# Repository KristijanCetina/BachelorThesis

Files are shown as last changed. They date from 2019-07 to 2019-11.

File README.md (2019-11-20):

# BachelorThesis

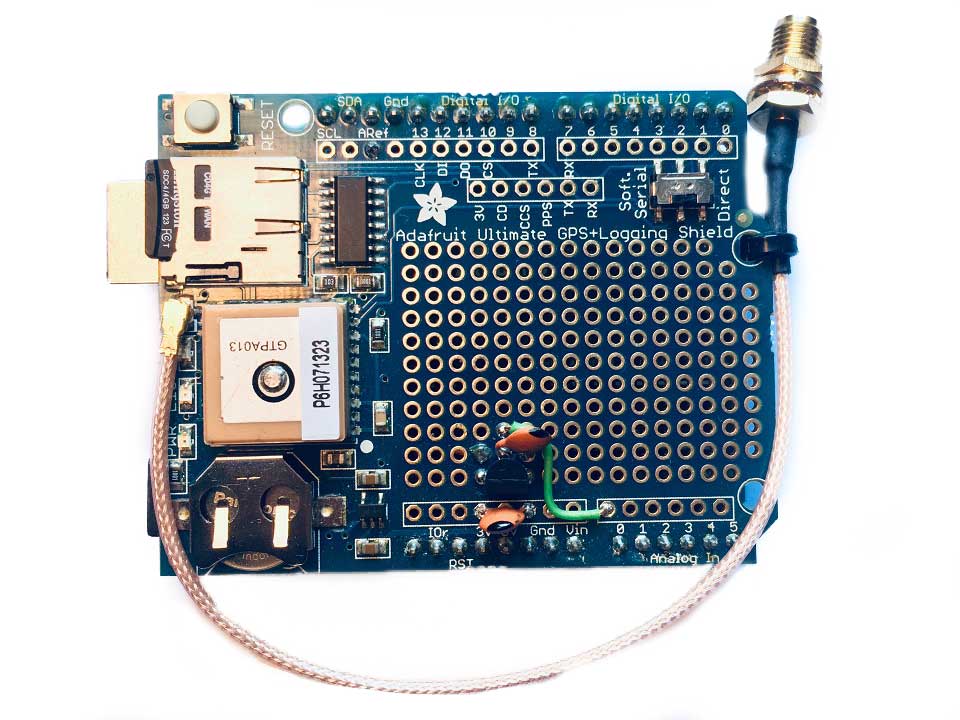
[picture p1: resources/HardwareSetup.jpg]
Hardwareski sklop

Završni rad stručnog studija Politehnike koji se izvodi pri [Istarskom Veleučilištu](https://www.iv.hr/)

Na sljedećem linku je dostupna [PDF verzija rada](https://github.com/KristijanCetina/BachelorThesis/blob/master/report/Zavr%C5%A1niRad-KristijanCetina.pdf)

Najlakši način za preuzeti ovaj rad ukoliko koristite git je putem sljedeće naredbe

``` bash
git clone https://github.com/KristijanCetina/BachelorThesis.git [<directory>]
```

pri čemu je `[<directory>]` neobavezan parameter - željeno ime projekta.

U suprotnom možete preuzeti cijeli kao .zip datoteku klikom na `Download`

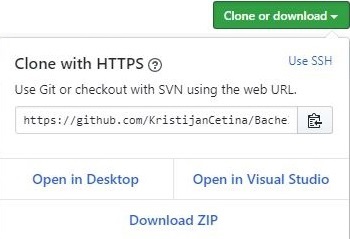
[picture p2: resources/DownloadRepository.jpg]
Download


## Summary

Prikupljanje, obrada i vizualizacija podataka nalazi se na svakom koraku našega života.
U ovom radu prikazan je postupak izrade snimača podataka koristeći Arduino platformu te obrada podataka koristeći isključivo alate otvorenog i slobodnog koda.
Hardwareska platforma trenutno koristi GPS prijemnik i temperaturni senzor te se u budućnosti planira povećanje broja senzora.
Podatci koji se skupljaju na uređaju spremaju se lokalno na memorijsku karticu ne bi li se kasnije analizirali na računalu pri čemu se koristi programski jezik Python unutar Jupyter notebook okruženja uz pomoć Pandas, NumPy i Matplotlib biblioteka.
Izrađeni alat za analizu radi na svim popularnim operacijskim sustavima danas u upotrebi.

U duhu otvorenog koda i dobre prakse znanstvene zajednice ovaj rad je napisan koristeći LaTeX sustav te je kompletan rad hostan na GitHub-u i slobodano dostupan svim zainteresiranim stranama koji žele nastaviti rad na ovoj temi.

### Ključne riječi

`Arduino, Python, Matplotlib, open-source, obrada podataka`

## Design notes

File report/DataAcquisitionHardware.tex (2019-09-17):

\chapter{Prikupljanje podataka - hardware}\label{ch:Hardware}
\begin{figure}[h]
\begin{center}
.jpg}
\caption{Izgled korištenog hardwareskog sklopa}\label{pic:HardwareSetup}
\end{center}
\end{figure}
Na slici \ref{pic:HardwareSetup} prikazan je zgotovljeni hardwareski sklop korišten u ovom radu.
Ispod GPS prijemnika s utorom za microSD karticu i prototipnim područjem nalazi se Arduino UNO mikrokontroler.
Za bolji prijem signala korištena je GPS antena, a za spajanje se koristi adapterski kabel (\textit{pigtail}).
Dodatno se može vidjeti temperaturni senzor TMP36 zajedno s filter kondenzatorima.

U prilogu \ref{ArduinoSource} prikazan je cjeloviti izvorni kod koji se izvšvana na Arduino mikrokontroleru.

\section{GPS logging shield}

\begin{figure}
.pdf}
\caption{Shema Adafruit GPS Logger Shield}\label{shema:AdafruitLoggerShield}
\end{figure}

Na shemi \ref{shema:AdafruitLoggerShield} nalazi se shema gotovog elektroničkog sklopa kako dolazi iz tvornice\footnote{Kompletna dokumentacija dostupna je na \url{https://learn.adafruit.com/adafruit-ultimate-gps-logger-shield?view=all}}$^,$\footnote{GitHub repozitorij korištene verzije dostupan na \url{https://github.com/adafruit/Adafruit-GPS-Logger-Shield-PCB}}.
Na samoj tiskanoj pločici postoji takozvano prototipno područje za dodavanje vanjskih elemanata čiji je raster 2.54 mm koji odgovara standardu \textit{through-hole} elemenata.
Na to područje je dodan temperaturni senzor TMP36\footnote{Datasheet dostupan na \url{https://github.com/KristijanCetina/BachelorThesis/blob/master/resources/TMP35_36_37.pdf}}\label{ftn:TMP36Datasheet} zajedno s dodatnim pasivnim elementima koji služe kao filter smetnji koje se javljaju u radu zbog okoline.
Shema spoja je prikazana na slici \ref{shema:TMP36}.

\section{Prikupljanje podataka o temperaturi}\label{sec:TempData}
\begin{figure}[!ht]
\begin{center}
.jpg}
\caption{Shema spoja TMP36 senzora}\label{shema:TMP36}
\end{center}
\end{figure}
Kako svaki elektronički sklop ima definirani raspon radne temperature važno je znati u kojim se uvjetima isti nalazi.
Ukoliko je temperatura previsoka, može se uključiti aktivno hlađenje, ili, ako se unaprijed zna da će se sklop nalaziti pod povišenom radnom temperaturom tada se može konstrurati adekvatan sustav hlađenja.
Isto vrijedi za prenisku temperaturu.
Prema ranije spomenutoj shemi \ref{shema:TMP36}, dodan je temperaturni senzor koji mjeri radnu temperaturu okoline uređaja.
Pri testiranju, ova vrsta senzora pokazala se veoma pouzdanom, uz minimalno samozagrijavanje koje bi utjecalo na točnost mjerene veličine, ali je isto tako pokazala vrlo brze promjene izlazne vrijednosti koja može imati uzrok u vanjskim smetnjama.
Kako bi se otklonio taj problem primijenjena su dva rješenja.
Prvi je hardwareski filter - kondenzatori koji si prikazani na shemi \ref{shema:TMP36}, a drugi je softwareski filter.
Tvornički podatci o izlaznom naponu šuma mogu se pronaći u datasheetu uređaja, slika 20.
Na slici \ref{data:RawWithOutCaps} prikazane su izlazne vrijednosti senzora bez ikakvog filtriranja i obrade.
Frekvencija uzorkovanja je 10Hz (10 očitanja u sekundi)
Svakako nije realno za očekivati da se temperatura mjenja sukladno očitanim vrijednostima.

\subsection{Softwareski filter}
Softwareski filter radi na principu očitavanja 10 vrijedosti sa senzora te ih sprema u polje.
Potom ih sortira po veličini i uzima medijan\footnote{Medijan (mediana, centralna vrijednost) je pojam iz statistike koji određuje sredinu distribucije.
Pola vrijednosti skupa (distribucije) nalazi se iznad mediane, a pola ispod} vrijednost kao točnu temperaturu.
Time se eliminiraju sve vrlo visoke i vrlo niske vrijednosti koje se mogu pojaviti zbog šuma u signalu.
Vrijednosti se čitaju svakih 100 ms te uz računanje na bazi 10 vrijednosti daju frekvenciju od 1 očitanja u sekundi koja odgovara i frekvenciji uzorkovanja podataka s GPS senzora.
Prilikom testiranja utvrđeno je da veći broj uzoraka ne doprinosti kvaliteti izmjerenih vrijednosti, dok se pri manjem broju uzoraka može se potkrasti poneka nerealna vrijenosti.
Kako je očekivano vrijeme promjene temperature značajno duže od 1 sekunde onda su prihvaćene navedene vrijednosti i metoda filtriranja.
Na slici \ref{data:FilteredWithOutCaps} prikazane su izlazne vrijednosti senzora nakon primjene opisanog softwareskog filtera.
Primijeti se značajno manje skokova od nečega što se može smatrati stvarnom vrijednosti. 

\begin{figure}[!h]
\begin{minipage}{0.49\linewidth}
.jpg}
\caption{Vrijednosti senzora bez \mbox{filtriranja}}\label{data:RawWithOutCaps}
\end{minipage}
\hfill
\begin{minipage}{0.49\linewidth}
.jpg}
\caption{Vrijednosti senzora sa \mbox{softwareskim} filtriranja}\label{data:FilteredWithOutCaps}
\end{minipage}
\end{figure}

\subsection{Hardwareski filter}
Filter je jednostavna mreža keramičkih kondenzatora vrijednosti $10 pF$ koji su spojeni što bliže senzoru između izvoda za napajanje i izlaza senzora prema točki nultog potencijala (\textit{GND, masa}) kako bi apsorbirali eventualne smetnje.
Iako je softwareski filter u nekim situacijama dovoljno dobar, ovo jednostavno i jeftino rješenje daje dodatni sloj filtriranja koji za posljedicu ima vrlo glatko očitanje temperature bez skokova u vrijednostima.

Primjenom kombinacije softwareskog i hardwareskog filtriranja postignuta je vrlo zadovoljavajuća karakteristika dobivenih stabilnih vrijednosti bez nerealnih skokova i s vrlo glatkom tranzicijom kod grijanja ili hlađenja sklopa. Dobivene vrijednosti prikazane su na slici \ref{data:FilteredWithCaps}.
\begin{figure}[!h]\begin{center}
.jpg}
\caption{Vrijednosti senzora primjenom kombinacije Sw i Hw filtera}\label{data:FilteredWithCaps}
\end{center}\end{figure}

\section{Prikupljanje GPS podataka}
GPS\footnote{Global Positioning System - Sustav globalnog pozicioniranja} je javni sustav u vlasništvu vlade SAD-a\footnote{\url{https://www.gps.gov}} koji služi globalnom pozicioniranju temeljen na satelitima s atomskim satovima koji odašilju vrlo točno i precizno trenutno vrijeme te su sinkronizirani sa zemaljskim satovima. 
Bilo kakva odstupanja se korigiraju na dnevnoj bazi.
Prijemnik prima signal satelita te izračunava točnu poziciju temeljenu na poznatoj poziciji satelita i razlikama u primljenim vremenima od svakog satelita.
Minimalno su potrebna 3 satelita za dobivanje koordinata i 4 satelita za dobiti pozicija o nadmorskoj visini prijemnika.

U ovom radu korišten je GPS chip MTK3339\footnote{\url{https://cdn-shop.adafruit.com/datasheets/GlobalTop-FGPMMOPA6C-Datasheet-V0A-Preliminary.pdf}} integriran na prije spomenuti Adafruit Ultimate GPS Logger Shield.

Kao koristan izlaz prijemnik daje NMEA\footnote{\url{https://www.nmea.org/content/STANDARDS/NMEA_0183_Standard}} rečenicu. 
Ovisno o potrebnim podatcima, mogu se koristiti razne rečenice, a u ovoj primjeni korištena je \$GPRMC\footnote{\url{http://aprs.gids.nl/nmea/}} koja daje minimalne potrebne podatke, a među kojima su vrijeme (UTC) i datum, trenutna pozicija i brzina.
Primjer \$GPRMC rečenice je \begin{verbatim}
$GPRMC,053005.000,A,4457.8784,N,01356.1351,E,36.41,124.90,310719,,,A*58
\end{verbatim}
pri čemu je:
\begin{tabbing}
\hspace{80pt}\=\kill
 \$GPRMC \> Oznaka rečenice \\ 
 053005.000 \> UTC vrijeme (7:30:05 lokalno)\\ 
 A \> Oznaka valjanosti, A = OK, V = warning \\ 
 4457.8784,N \> Zemljopisna širina \\ 
 01356.1351,E \> Zemljopins dužina \\ 
 36.41 \> Brzina u čvorovima ($\approx 67 km/h$)\\ 
 124.90 \> Smjer kretanja \\
 310719 \> Datum (31. srpnja 2019.)\\
 A*58 \> Checksum (kontrolni broj)
\end{tabbing} 
Prilikom provjere primljenih podataka obavezno se provjerava
\begin{itemize}
\item da li primljeni checksum odgovara izračunanom za datu rečenicu kako bi se izbjegle pogreške u komunikaciji,
\item je li oznaka valjanosti \textit{A} što znači da uređaj ima prijem s dovoljnog broj satelita da se primljenim podatcima može vjerovati.
\end{itemize}
Provjeru valjanosti i checksuma vrši biblioteka dostupna za Arduino platformu zajedno s ostalom dokumentacijom uređaja te nije bilo potrebno pisati poseban kod koji će to raditi.

\section{Spremanje podataka na memorijsku karticu}
Na korištenom Adafruit Ultimate GPS Logger Shieldu postoji utor za microSD memorijsku karticu koja se koristi za zapisivanje prikupljenih podataka kako bi se isti mogli kasnije obraditi i prikazati.
Sustav prikupljene podatke sprema na memorijsku karticu u .csv \footnote{Comma Separated Values} formatu pogodnim za kasniju obradu putem Excel programskog alata ili drugih alata za obradu i vizualizaciju podataka.
Svaki red predstavlja jedan zapis, a u odnosu na ranije prikazanu \$GPRMC rečenicu, na kraju je dodan i podatak o trenutnoj temperaturi u $^\circ C$ koja je očitana sa senzora opisanog u poglavlju \ref{sec:TempData}.
Frekvencija zapisivanja podatka je postavljena na 1 zapis u sekundi.
Datoteka se automatski kreira prilikom uključivanja sklopa ako je SD kartica prisutna.
Ime datoteke je GPSLOG\textit{XX}.csv pri čemu je \textit{XX} broj koji počinje od 00 i uvećava je za 1 kod svakog pokretanja. 
Testiranje je pokazalo da veličina datoteke s 10 sati ($\approx 36000$ zapisa) snimljenih podataka iznosi otprilike 2.7 MB.

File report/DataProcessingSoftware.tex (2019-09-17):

\chapter{Obrada podataka - software}\label{ch:Software}
Kako je već spomenuto u uvodu i opisu korištenih tehnologija, analiza podataka izrađena je koristeći Python programski jezik unutar Jupyter Notebook interaktivne bilježnice uz dodatak Numpy biblioteke za numeričku analizu i Matplotlib biblioteke za izradu grafova.

\section{Prikaz podataka vozila u kretanju}
Kao prvi primjer obrade podataka izrađena je analiza kretanja vozila i vizualizirani su prikupljeni podatci.
U dodatku \ref{AnalizaKretanjaVozila} prikazana je cjelokupna analiza podataka te demonstriran završni proizvod koji može biti dalje distribuiran u printanoj verziji ili preferirano u digitalnom obliku koji onda omogućava daljni rad na istome.

Koristeći razne tipove ćelija unutar Jupyter notebooka, stvorena je prikazana analiza.
Tip čelije \textit{Markdown} podržava formatiranje i sintaksu \texttt{.md} Markdown datoteke\footnote{\url{https://www.markdownguide.org/}}, a koje se koriste za opisni dio analize kako bi čitatelj znao o čemu se radi bez potrebe proučavanja programskog koda.

Tip ćelije \textit{Code} omogućuje unošenje i izvršavanje programskoga koda koji će napraviti neku željenu radnju.
Ćelije se mogu izvršavati jedno po jedna ili sve u sekvencijalnom nizu.

Na kraju postoje i \textit{Output} ćelije koje prikazuju izlazni rezultat izvršene \textit{code} ćelije.

Kako bi mogli koristiti navedene dodatne module u Python prvo ih je potrebno uvesti
\begin{lstlisting}[language=Python]
import pandas as pd
import matplotlib.pyplot as plt
from numpy import genfromtxt, arange, sin, pi
from matplotlib import style
from matplotlib import dates as mpl_dates
import numpy as np
from pandas.plotting import register_matplotlib_converters
register_matplotlib_converters()
\end{lstlisting}

Konvencija je da se NumPy biblioteka skrećeno imenuje \texttt{np} kako bi se olakšalo kasnije korištenje u radu.
Isto vrijedi i za ostale često korištene biblioteke.

Nakon toga potrebno je navesti koja se datoteka s podatcima koristi i nazvati stupce podataka 
\begin{lstlisting}[language=Python]
filename='GPSLOG10.CSV'
data=pd.read_csv(filename, header=None, delimiter=',',
names=['Sentence','Time','Validity','Latitue','NS','Longitude','EW',
'Speed','Direction','Date','NA1','NA2','Checksum','Temperature'])
\end{lstlisting}
Pri čemu je \texttt{GPSLOG10.CSV} ime datoteke u kojem su spremljeni podatci.

Nakon uvodnih radnji, spremni smo započeti s analizom podataka i vizualizcijom onih koje nas zanimaju.
U ovisnosti o željenim rezultatima ovisit će i potrebne operacije koje je potrebno poduzeti.
Ponekad su podatci već u takvom formatu da se mogu odmah koristiti, dok je ponekada potrebno napraviti veću ili manju manipulaciju nad njima kako bi bili pogodni za korištenje.
U svakom slučaju, vrlo je važno poznavati strukturu seta podataka koji se koristi kako bi se izbjegle pogreške zbog njegovog nepoznavanja ili korištenja krive mjerne jedinice.
Godine 1999., NASA je izgubila 125 milijuna vrijedan \textit{Mars Climate Orbiter} zbog previda pretvorbe jedinica\cite{sauser2009projects} što samo pokazuje koliko je to realna zamka u koju i najbolji svjetski stručnjaci mogu upasti.
U ovom slučaju, brzina je prikazana u čvorovima što odgovara prijeđenom putu od jedne nautičke milje u sat vremena.
Ukoliko želimo prikazati brzinu u $km/h$ potrebno je izvršiti pretvorbu jedinica.
Jedna nautička milja iznosi 1852 $m$ što znači da zapisanu brzinu treba pomnožiti s 1.852 kako bi dobili $km/s$.

\begin{figure}[!h]\begin{center}
.png}
\caption{Izrađeni graf kretanja vozila}\label{graf:Speed}
\end{center}\end{figure}

Obzirom da je uvijek korisno vizualizirati kretanje veličine na grafu tako je i u ovom radu napravljen graf promjene brzine u vremenu prikazan na \ref{graf:Speed}, što je koristeći Matplotlib vrlo jednostavno.
\begin{lstlisting}[language=Python]
plt.plot(data['Time'],data['Speed']*1.852, 'b-')
\end{lstlisting}
Pri čemu  \textit{data['Time']} predstavlja apcisu grafa, a \textit{data['Speed']} predstavlja ordinatu prikazanog grafa.
\textit{'b-'} je parametar kojim je definirana linija - linija plave boje.
Svaki graf treba biti propisno obilježen pa su tako i na ovom grafu označene vrijednosti i imena osi, prikazane mjerne jedinice i dodana legenda, iako je prikazana samo jedna veličina.

Dodatno, iz dostupnih podataka može se napraviti graf kretanja temperature koji je prikazan u kompletnoj analizi u dodatku \ref{AnalizaKretanjaVozila}.
Osim podataka koji se mogu prikazati grafički, možemo pogledati i ostale statističke podatke kao što su minimalna i maksimalna temperatura tijekom promatranog razdoblja.
\begin{lstlisting}[language=Python]
print ('Minimalna temperatura: ',np.min(data['Temperature']), 'C')
print ('Maximalna temperatura: ',np.max(data['Temperature']), 'C')
\end{lstlisting}
Ovdje su korištene ugrađene funkcije \texttt{min} i \texttt{max} NumPy biblioteke koje za parametar uzimaju set podataka temperature.

Zanima li nas prosječna temperatura tijekom promatranog razdoblja, tada i za to postoji funkcija koja nam olakšava rad.
Umjesto da zbrajamo sve elemente te zbroj dijelimo s brojem elemenata, jednostavno možemo koristiti
\begin{lstlisting}[language=Python]
print ('Prosjecna temperatura: ', '
{:.2f}'.format(np.mean(data['Temperature'])), 'C ',
'{:.2f}'.format(np.std(data['Temperature'])), 'C')
\end{lstlisting}
Pri čemu \texttt{np.mean} daje prosječnu temperaturu, a \texttt{np.std} daje standardnu devijaciju vrijednosti.
\texttt{'{:.2f}'.format} je opcija formatiranja stringa pomoću koje se prikazuje dva decimalna mjesta.

\section{Prikaz podataka lifta}
Analiza prikazana u dodatku \ref{VizualizacijaKretanjaLifta} vizualizira podatke prikupljene mobilnim telefonom koristeći aplikaciju \textit{phyphox}\footnote{\url{https://www.phyphox.org}}.
Korišten je modul koji očitava podatke s akcelerometra u sve 3 osi koordinatnog sustava.
Mobilni uređaj bio je prislonjen na bočni panel lifta i pokušano je postaviti ga da stoj okomito na smjer kretanja sa stražnjom stranom priljubljenim na panel kako bi se dobili čim točniji podatci bez unošenja pogreške zbog pomaknutih osi mobitela i lifta.
Izmjerene vrijednosti predstavljaju put od prizemlja do 5. kata zgrade na adresi Koparska 58, Pula.

Podatci su zatim spremljeni u .csv datoteku te je ista prenesena na računalo.
Datoteka je formatirana na način da ima imena vrijednosti u zaglavlju te su korišteni zadani nazivi, a polja odvojena znakom ";".

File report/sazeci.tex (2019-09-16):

\section*{Sažetak}\label{sazetak_hr}
\addcontentsline{toc}{chapter}{\nameref{sazetak_hr}}
Prikupljanje, obrada i vizualizacija podataka nalazi se na svakom koraku našega života.
U ovom radu prikazan je postupak izrade snimača podataka koristeči Arduino platformu te obrada podataka koristeći iskljućivo alate otvorenog i slobodnog koda.
Hardwareska platforma trenutno koristi GPS prijemnik i temperaturni senzor te se u budućnosti planira povećanje broja senzora.
Podatci koji se skupljaju na uređaju spremaju se lokalno na memorijsku karticu ne bi li se kasnije analizirali na računalu pri čemu se koristi programski jezik Python unutar Jupyter notebook okruženja uz pomoć Pandas, NumPy i Matplotlib biblioteka.
Izrađeni alat za analizu radi na svim popularnim operacijskim sustavima danas u upotrebi.

U duhu otvorenog koda i dobre prakse znanstvene zajednice ovaj rad je napisan koristeći \LaTeX{} sustav te je kompletan rad \textit{hostan} na GitHub-u i slobodano dostupan svim zainteresiranim stranama koji žele nastaviti rad na ovoj temi.

\subsection*{Ključne riječi}\label{kw_hr}
\addcontentsline{toc}{section}{\nameref{kw_hr}}
\textit{Arduino, Python, Matplotlib, open-source, obrada podataka}

\section*{Sommario}\label{sazetak_it}
\addcontentsline{toc}{chapter}{\nameref{sazetak_it}}
La raccolta, l’elaborazione e la visualizzazione dei dati è presente in ogni aspetto della nostra
vita.
In questa tesi è documentata la creazione di uno strumento per la raccolta dati creato su
piattaforma Arduino, e l’elaborazione dei dati raccolti usando esclusivamente strumenti \textit{Open Source}.
La piattaforma hardware attuale usa un ricevitore GPS ed un sensore di temperatura mentre per future evoluzioni è in programma l’incremento del numero di sensori. 
I dati raccolti dallo strumento vengono immagazzinati sulla scheda di memoria per poi essere analizzati sul computer.
Per l’analisi dei dati viene usato il linguaggio di programmazione Python sull' ambiente di programmazione Jupyter notebook, con l’ausilio di biblioteche Pandas, NumPy e Matplotlib.
Lo strumento qui descritto è compatibile con tutti i sistemi operativi piu popolari oggi in uso.

Nello spirito della filosofia Open Source e della cultura scientifica questa tesi e stata scritta usando il sistema \LaTeX{} ed è disponibile liberamente su GitHub per tutti coloro che fossero interessati a continuare il lavoro fatto su questo tema.

\subsection*{Parole chiave:}\label{kw_it}
\addcontentsline{toc}{section}{\nameref{kw_it}}
\textit{Arduino, Python, Matplotlib, open-source, analisi dati}

\section*{Abstract}\label{sazetak_en}
\addcontentsline{toc}{chapter}{\nameref{sazetak_en}}
Data acquisition, processing, and visualization are at every step of our lives.
This paper describes how to record data using an Arduino and analyze them using free and open-source (FOSS) tools exclusively.
The hardware platform is currently using a GPS receiver and a temperature sensor with the planned increase in the number of sensors in the future.
The data collected on the devices is stored locally to a memory card and subsequently analyzed on a computer.
The Python programming language within the Jupyter notebook environment was used for analysis with the help of the Pandas, NumPy and Matplotlib libraries.
The created analysis tool works on all today popular operating systems.

In the spirit of the open-source and good practice of the scientific community, this paper was written using the \LaTeX{} system and a complete project is hosted on GitHub freely available to all interested parties who wish to work on these topic.

\subsection*{Keywords:}\label{kw_en}
\addcontentsline{toc}{section}{\nameref{kw_en}}
\textit{Arduino, Python, Matplotlib, open-source, data analysis}

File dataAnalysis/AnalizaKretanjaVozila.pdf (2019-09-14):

# AnalizaKretanjaVozila

## September 14, 2019

## 1 Analiza podataka kretanja vozila iz .csv filea

### Demo kako uz pomoc python programskog jezika i matplotlib biblioteke za prikaz grafova Prvo uvezemo potrbne bibliteke

[1]: import pandas as pd
import matplotlib.pyplot as plt
import matplotlib as mpl
from numpy import genfromtxt, arange, sin, pi from matplotlib import style
from matplotlib import dates as mpl_dates
import numpy as np
from pandas.plotting import register_matplotlib_converters register_matplotlib_converters()

Unese se ime datoteke s podacima i mapiraju se polja sukladno zapisanome.
U ovom primjeru podaci su razdvojeni s znakom ‘,’ ali cesti je slucaj kada su podaci odvojeni

### nekim drugim znakom te se to treba posebno naznaciti kako bi program znao granice izmedu

polja.

[2]: filename='GPSLOG10.CSV'
#plt.style.use('ggplot')

data=pd.read_csv(filename, header=None, delimiter=',',␣ ,→names=['Sentence','Time','Validity','Latitude','NS', ␣
,→'Longitude','EW','Speed','Direction','Date',
␣
,→'NA1','NA2','Checksum','Temperature'])

### 1.1 Line plot

### Sada smo spremni za prikazati prikupljene podatke. Prvo mozemo prikazati jednostavan s/t

graf - brzinu u vremenu. Kako je brzina zapisana u cvorovima, a mi je zelimo prikazati u km/h potrebno izvrsiti konverziju. 1 nauticna milja odgovara 1.852 km.
Svaki graf treba imati oznacene osi. S komandom plt.xlabel i ylabel oznacili smo osi grafa i analogno tome imenovan je i graf kako bi citatelj znao to graf predstavlja. Naravno, pojedinacni grafovi se mogu posebno spremiti u visokoj rezoluciji i zeljenom formatu za kasniju upotrebu.

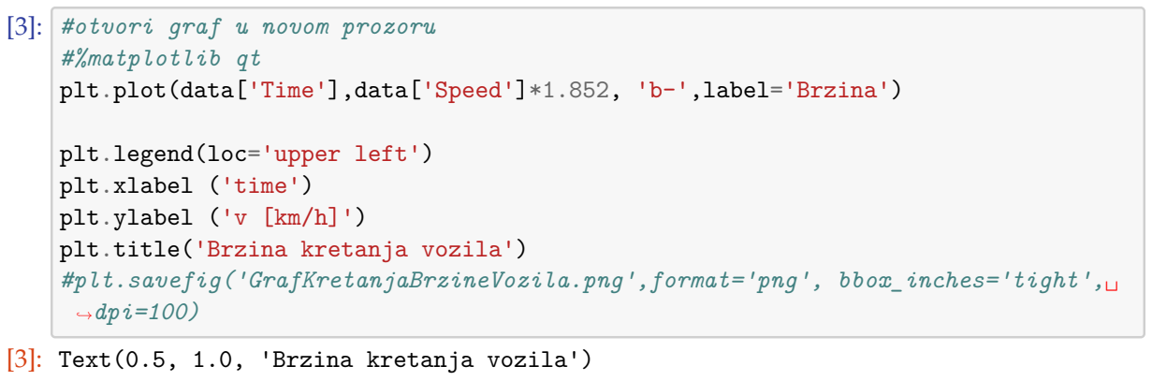
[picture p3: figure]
[3]: #otvori graf u novom prozoru; #%matplotlib qt; plt.plot(data['Time'],data['Speed']*1.852, 'b-',label='Brzina'); plt.legend(loc='upper left'); plt.xlabel ('time'); plt.ylabel ('v [km/h]'); plt.title('Brzina kretanja vozila'); #plt.savefig('GrafKretanjaBrzineVozila.png',format='png', bbox_inches='tight',␣; ,→dpi=100)

[3]: Text(0.5, 1.0, 'Brzina kretanja vozila')

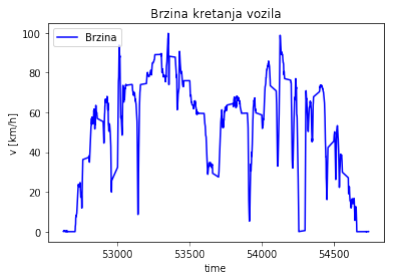
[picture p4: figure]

Dodatno se mogu izracunati i pogledati razni podaci koje nas zanimaju.
Ako npr. zelimo znati koja je bila maksimalna brzina kojom se vozilo kretalo to se moze vidjeti

### na sljedeci nacin:

[4]: print('Maksimalna brzina = ',np.max(data['Speed']*1.852) , 'km/h')

Maksimalna brzina = 99.73020000000001 km/h

Ako nas zanimaju podaci o temperaturi moguce je cak koristiti i ugradene statisticke funkcije

### za izracunati zeljene podatke

[8]: # prikazi graf inline
%matplotlib inline plt.rcParams["figure.figsize"] = (10,5) plt.plot(data['Time'],data['Temperature'], 'g', linewidth=2,label='Temperatura')

plt.legend(loc='upper left')
plt.xlabel ('time')
plt.ylabel ('$\Theta \, [^\circ C]$')
plt.title('Temperatura tokom puta')

print ('Minimalna temperatura: ',np.min(data['Temperature']), 'řC') print ('Maximalna temperatura: ',np.max(data['Temperature']), 'řC')
print ('Razlika temperature: ',np.max(data['Temperature']) - np. ,→min(data['Temperature']), 'řC')
print ('Razlika temperature: ','{:.2f}'.format(np.ptp(data['Temperature'])),␣ ,→'řC')
print ('Prosjecna temperatura: ', '{:.2f}'.format(np. ,→mean(data['Temperature'])), 'řC ś ', '{:.2f}'.format(np.std(data['Temperature'])), 'řC')
Minimalna temperatura: | 25.73 řC
Maximalna temperatura: | 27.99 řC
Razlika temperature: | 2.259999999999998 řC
Razlika temperature: | 2.26 řC
Prosjecna temperatura: | 26.64 řC ś | 0.57 řC

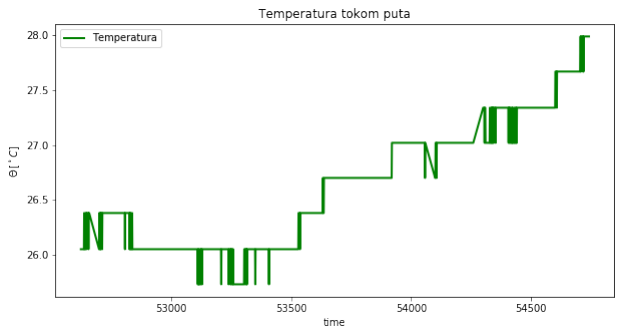
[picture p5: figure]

Ako elimo plotati ove dvije veliine na istom grafu da vizualno utvrdimo postojanje korelacije

### moemo kreirati subplot

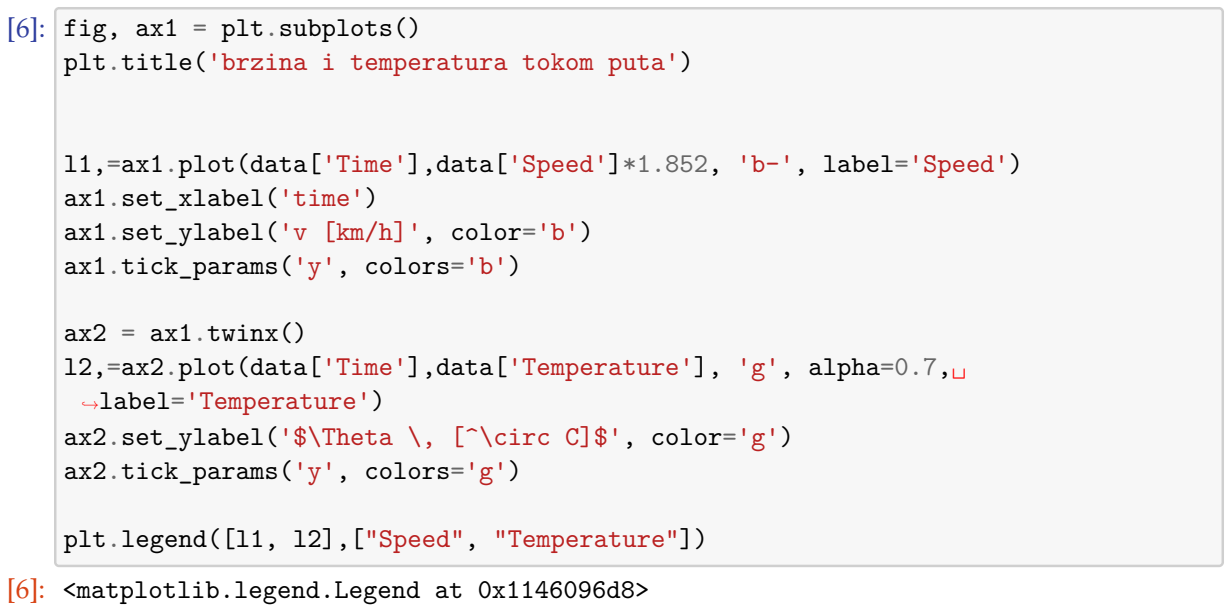
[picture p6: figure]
[6]: fig, ax1 = plt.subplots(); plt.title('brzina i temperatura tokom puta'); l1,=ax1.plot(data['Time'],data['Speed']*1.852, 'b-', label='Speed'); ax1.set_xlabel('time'); ax1.set_ylabel('v [km/h]', color='b'); ax1.tick_params('y', colors='b'); ax2 = ax1.twinx(); l2,=ax2.plot(data['Time'],data['Temperature'], 'g', alpha=0.7,␣; ,→label='Temperature'); ax2.set_ylabel('$\Theta \, [^\circ C]$', color='g'); ax2.tick_params('y', colors='g'); plt.legend([l1, l2],["Speed", "Temperature"]); [6]: <matplotlib.legend.Legend at 0x1146096d8>
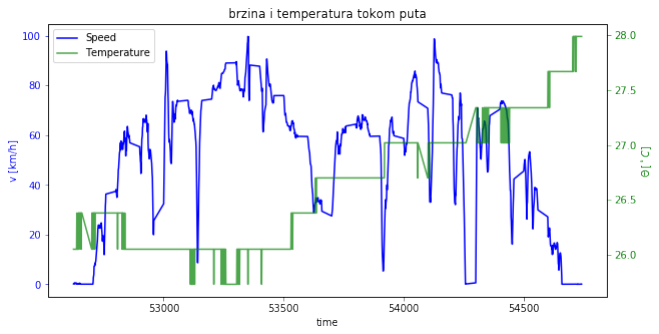
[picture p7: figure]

Uvidom u graf ne mozemo vizualno utvdriti postoje zavisnosti jedve velicine o drugoj, ali se moze primjetiti trend porasta temperature s vremenom. Koji je tocan uzrok tome treba dodatno istraziti sto nije predmet ovog rada.

### 1.2 Scatter plot

Koristeci funkciju scatter koji za razliku od line ne spaja susjedne toke linijom moemo prikazati kretanje vozila u koordinatnom sustavu.

### Dodavanjem vrijednosti parametru c (color) moemo prikazati i dodatnu dimenziju, a to je u

ovom sluaju brzina kretanja prikazana putem obojene skale.

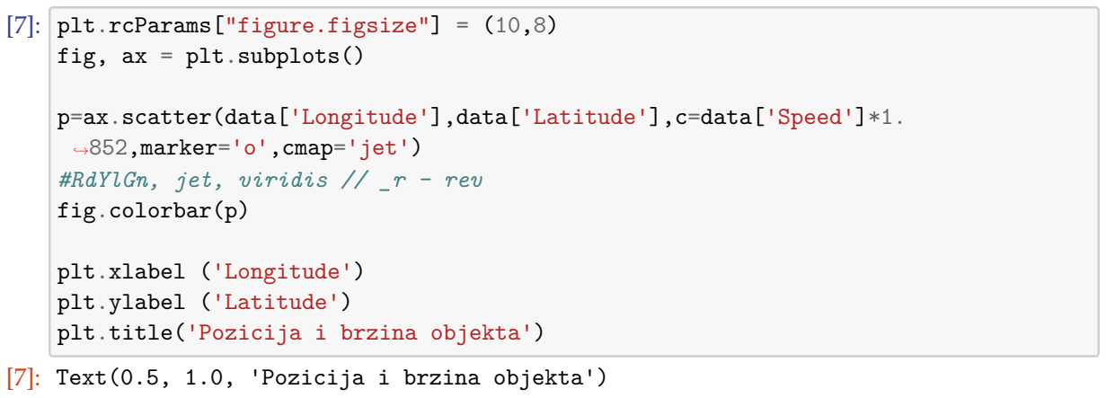
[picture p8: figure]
[7]: plt.rcParams["figure.figsize"] = (10,8); fig, ax = plt.subplots(); p=ax.scatter(data['Longitude'],data['Latitude'],c=data['Speed']*1.; ,→852,marker='o',cmap='jet'); #RdYlGn, jet, viridis // _r - rev; fig.colorbar(p); plt.xlabel ('Longitude'); plt.ylabel ('Latitude'); plt.title('Pozicija i brzina objekta')

[7]: Text(0.5, 1.0, 'Pozicija i brzina objekta')

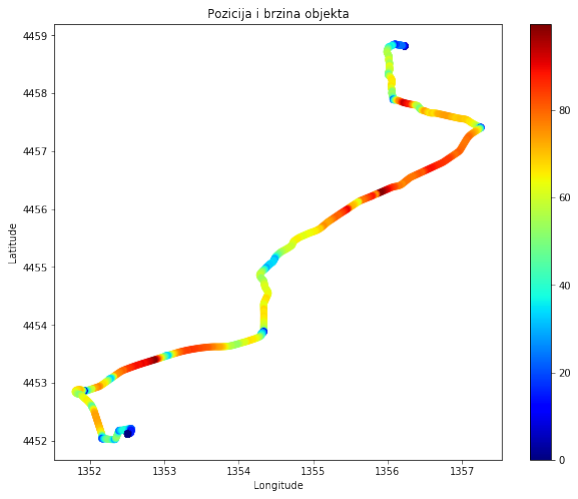
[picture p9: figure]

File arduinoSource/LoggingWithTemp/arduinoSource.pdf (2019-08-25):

...rThesis\arduinoSource\LoggingWithTemp\LoggingWithTemp.c | 1
#include <SPI.h>

#include <Arduino.h>

#include <Adafruit_GPS.h>

#include <SoftwareSerial.h>

#include <SD.h>

#include <avr/sleep.h>

#include <Wire.h> | // this #include still required because the RTClib

depends on it
#include "RTClib.h"

int voltage;
int Temperatura;
int TempSenzor = A0;

#define aref_voltage 3.3

float temp[10] = { 0 };

float i = 0;
int n = 0;
float median = 0;

SoftwareSerial mySerial(8, 7);
Adafruit_GPS GPS(&mySerial);

// Set GPSECHO to 'false' to turn off echoing the GPS data to the Serial console
// Set to 'true' if you want to debug and listen to the raw GPS sentences #define GPSECHO false
/* set to true to only log to SD when GPS has a fix, for debugging, keep it false */
#define LOG_FIXONLY true

// this keeps track of whether we're using the interrupt
// off by default!
#ifndef ESP8266 // Sadly not on ESP8266

boolean usingInterrupt = false;
#endif

// Set the pins used
#define chipSelect 10

#define ledPin 13

File logfile;

RTC_DS1307 RTC; // define the Real Time Clock object RTC_Millis rtc;

char timestamp[30];
// call back for file timestamps
void dateTime(uint16_t* date, uint16_t* time) {
DateTime now = RTC.now();
sprintf(timestamp, "%02d:%02d:%02d %2d/%2d/%2d \n", now.hour(),now.minute (),now.second(),now.month(),now.day(),now.year()-2000); Serial.println("yy");
Serial.println(timestamp);
// return date using FAT_DATE macro to format fields

...rThesis\arduinoSource\LoggingWithTemp\LoggingWithTemp.c | 2
*date = FAT_DATE(now.year(), now.month(), now.day());

// return time using FAT_TIME macro to format fields
*time = FAT_TIME(now.hour(), now.minute(), now.second());
}

// read a Hex value and return the decimal equivalent uint8_t parseHex(char c) {
if (c < '0')
return 0;
if (c <= '9')
return c - '0';
if (c < 'A')
return 0;
if (c <= 'F')
return (c - 'A')+10;
}

// blink out an error code void error(uint8_t errno) { /*
if (SD.errorCode()) {
putstring("SD error: ");
Serial.print(card.errorCode(), HEX); Serial.print(',');
Serial.println(card.errorData(), HEX); }
*/
while(1) {
uint8_t i;
for (i=0; i<errno; i++) {
digitalWrite(ledPin, HIGH); delay(100);
digitalWrite(ledPin, LOW); delay(100);
}
for (i=errno; i<10; i++) { delay(200);
}
}
}

void setup() {
Wire.begin();
if (!RTC.begin()) {
Serial.println("RTC failed");
while(1);
};
// connect at 115200 so we can read the GPS fast enough and echo without dropping chars
// also spit it out
Serial.begin(115200);
Serial.println("\r\nUltimate GPSlogger Shield");
pinMode(ledPin, OUTPUT);
pinMode(TempSenzor, INPUT); //postavi izvod TempSenzor (A0) kao ulazni analogReference(EXTERNAL); // Koristim 3.3 Vref

...rThesis\arduinoSource\LoggingWithTemp\LoggingWithTemp.c | 3

// make sure that the default chip select pin is set to
// output, even if you don't use it:
pinMode(10, OUTPUT);

if (!SD.begin(chipSelect)) {
Serial.println("Card init. failed!"); error(2);
}
char filename[15];
strcpy(filename, "GPSLOG00.csv"); for (uint8_t i = 0; i < 100; i++) {
filename[6] = '0' + i/10;
filename[7] = '0' + i%10;
// create if does not exist, do not open existing, write, sync after write if (! SD.exists(filename)) {
break;
}
}

logfile = SD.open(filename, FILE_WRITE); if( ! logfile ) {
Serial.print("Couldnt create "); Serial.println(filename);
error(3);
}
Serial.print("Writing to "); Serial.println(filename);

// connect to the GPS at the desired rate
GPS.begin(9600);

// uncomment this line to turn on RMC (recommended minimum) and GGA (fix data) including altitude
//GPS.sendCommand(PMTK_SET_NMEA_OUTPUT_RMCGGA);
// uncomment this line to turn on only the "minimum recommended" data GPS.sendCommand(PMTK_SET_NMEA_OUTPUT_RMCONLY);
// Set the update rate
GPS.sendCommand(PMTK_SET_NMEA_UPDATE_1HZ); // 100 millihertz (once every

### 10 seconds), 1Hz or 5Hz update rate

// Turn off updates on antenna status, if the firmware permits it GPS.sendCommand(PGCMD_NOANTENNA);
// the nice thing about this code is you can have a timer0 interrupt go off // every 1 millisecond, and read data from the GPS for you. that makes the // loop code a heck of a lot easier!
#ifndef ESP8266 // Not on ESP8266

useInterrupt(true);
#endif

Serial.println("Ready!");
}

// Interrupt is called once a millisecond, looks for any new GPS data, and stores it
#ifndef ESP8266 // Not on ESP8266

ISR(TIMER0_COMPA_vect) {
char c = GPS.read();

...rThesis\arduinoSource\LoggingWithTemp\LoggingWithTemp.c | 4
// if you want to debug, this is a good time to do it!
#ifdef UDR0

if (GPSECHO)
if (c) UDR0 = c;
// writing direct to UDR0 is much much faster than Serial.print // but only one character can be written at a time.
#endif

}

void useInterrupt(boolean v) {
if (v) {
// Timer0 is already used for millis() - we'll just interrupt somewhere // in the middle and call the "Compare A" function above
OCR0A = 0xAF;
TIMSK0 |= _BV(OCIE0A);
usingInterrupt = true;
}
else {
// do not call the interrupt function COMPA anymore TIMSK0 &= ~_BV(OCIE0A);
usingInterrupt = false;
}
}
#endif // ESP8266

// function to sort the array in ascending order void Array_sort(float *array, int n)
{
// declare some local variables
int i = 0, j = 0, temp = 0;
for (i = 0; i<n; i++)
{
for (j = 0; j<n - 1; j++)
{
if (array[j]>array[j + 1]) {
temp = array[j];
array[j] = array[j + 1];
array[j + 1] = temp;
}
}
}
}

float Find_median(float array[], int n) {
float median = 0;
// if number of elements are even
if (n % 2 == 0)
median = (array[(n - 1) / 2] + array[n / 2]) / 2.0; // if number of elements are odd
else
median = array[n / 2];
return median;
}

...rThesis\arduinoSource\LoggingWithTemp\LoggingWithTemp.c | 5
void loop(){
DateTime now = rtc.now();
if (! usingInterrupt) {
// read data from the GPS in the 'main loop'
char c = GPS.read();
// if you want to debug, this is a good time to do it! if (GPSECHO)
if (c) Serial.print(c);
}

// if a sentence is received, we can check the checksum, parse it...
if (GPS.newNMEAreceived()) {
char *stringptr = GPS.lastNMEA();

if (!GPS.parse(stringptr)) // this also sets the newNMEAreceived() flag to false
return; // we can fail to parse a sentence in which case we should just wait for another

// Sentence parsed!
Serial.println("OK");
if (LOG_FIXONLY && !GPS.fix) { Serial.print("No Fix");
return;
}

float voltage = analogRead(TempSenzor) * 3.3; //ocitava vrijednosti izvoda (A0)
voltage /= 1024.0; //10bit ADC
float Temperatura = (voltage - 0.5) * 100;
Serial.print("Trenutno: "); Serial.println(Temperatura);

// Rad. lets log it!
Serial.println("Log");

char tempBuff[5];
dtostrf(Temperatura,0,2,tempBuff); uint8_t tempSize = strlen(tempBuff);

//logfile.flush();

// ovaj blok kao dela pa pomalo s tim :-)
uint8_t stringsize = strlen(stringptr);// + tempSize; if (stringsize != logfile.write((uint8_t *)stringptr,
stringsize)) //write the string to the SD file
error(4);
if (strstr(stringptr, "RMC") || strstr(stringptr, "GGA") ) logfile.flush ();
logfile.write(tempBuff);
Serial.println();

}
}

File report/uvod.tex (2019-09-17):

\chapter{Uvod i opis zadatka}\label{OpisIOgranicenja}
Tema ovog rada proizašla je iz autorove želje za proučavanjem tematike te kao gorljivim poklonikom metode učenja kroz praktičan rad i primjenu stečenog znanja i iskustva na rješavanje realnog problema.
Dodatno, autorova je želja implementirati stečena znanja i razvijeni hardware i software u budućim projektima koje ima na umu.
Koristeći dostupna i otvorena znanja značajno je lakše razvijati projekte, a otvarajući rad ostalim zainteresiranom stranama, omogućava se kolaboracija na usavršavanju projekta ili stvaranju baze za druge, kompeksnije projekte.

Arduino platforma odabrana je za korištenje u hardwareskom djelu rada jer ista predstavlja relativno jednostavan i povoljan pristup te uz veliki izbor dodatnih gotovih pločica za proširivanje mogućnosti (\textit{shields}) s otvorenom dokumentacijom logičan je izbor.

Na softwareskoj strani izbor je pao na programski jezik Python te dodatne biblioteke Matplotlib i NumPy koje su isto tako otvorenog koda i besplatne za korištenje i dovoljno jednostavne za učenje.
Dodajmo tome popularnost među akademskom i znanstvenom zajednicom isti se nameću kao logičan izbor.

\section{Opis i definicija problema}
Pri proučavanju bilo kojeg inženjerskog ili znanstvenog problema potrebno je prikupiti dovoljnu količinu podataka te iste analizirati i na reprezentativan način prikazati u pokušaju razumjevanja problema.
GPS je globalno dostupan sustav putem kojim se mogu prikupiti dovoljno precizni podaci za civilnu primjenu te je format podataka standardiziran čime je omogućeno korištenje i standardnih metoda analize podataka.
Ovisno o promatranom problemu, potrebni su razni dodatni podatci koje pružaju razni senzori.
Temperatura je jedan o njih te je u ovom radu korišten klasični TMP36 temperaturni senzor i obrađeni podaci koji su skupljeni putem navedenog senzora.

\section{Cilj i svrha rada}
Cilj ovog rada bio je izraditi jednostavni snimač podataka (\textit{datalogger}) koji će spremati GPS podatke zajedno s podatcima prikupljenima s instaliranih senzora za kasniju analizu.
Izrađeni uređaj namijenjen je kao snimač podataka u kompleksnijem sklopu koji se može koristiti kad god postoji potreba za loggiranje podataka.
Uređaj je namijenjen zadovoljavanju širokog spektra potreba koje se mogu javiti bilo u industriji npr. prilikom praćenja pošiljki ili prilikom skupljanja podataka u istraživačke svrhe kako bi se razumio širi problem.

Sklop je temeljen na Arduino platformi koja omogućava lak razvoj prototipova uz široku dostupnost gotovih dodatnih modula (\textit{shields}) koji se jednostavno spajaju na bazno mikroračunalo.

Prikupljeni podatci spremaju se na SD karticu uređaja u datoteku za kasniju obradu i analazu.
Prikupljeni podaci se uz pomoć programskog jezika Python i dodatnih modula za statističku i numeričku analizu kao što su Pandas i Matplotlib obrađuju kroz sučelje interaktivne bilježnice Jupyter Notebook.
Pristup obrade putem interaktivne bilježnice uz korištenje raznih tipova čelija kao što su \textit{Code Cells, Markdown Cells i Raw Cells} omogućava lakšu vizualizaciju i pregled samog rada koji je pogodan za kasnije dijeljenje svim zainteresiranim stranama koji žele pregledati ili nastaviti rad na analizi.

\section{Hipoteza rada}
Hipoteza ovog rada je da primjena pristupa otvorenog i slobodnog koda (računalnog koda, metode obrade podataka, algoritama i shema hardwareskog sklopa) omogućava izradu funkcionalnog sustava uz prihvatljive troškove i skromne resurse.

\section{Metode rada}
Tijekom izrade ovoga rada korištene su različite znanstveno-istraživačke metode od kojih je svaka najprikladnija postavljenom izazovu, a one su:
\begin{itemize}
\item Istraživačka metoda – za stjecanje uvida u zadane okvire zadatka
\item Metoda logičke analize i sinteze – za prikupljanje podataka iz literature
\item Deskriptivna metoda – za izradu uvodnog i završnog dijela projektnog zadatka
\item Eksperimentalna metoda - u potrazi za optimalnim rješenjima za zadani dio problema
\end{itemize}

\section{Struktura rada}
Struktura ovoga rada podjeljena je u logičke cjeline.
Nakon uvoda i objašnjavanja rada, u poglavlju \ref{technologyStack} opisan je korišten pristup i primijenjene tehnologije kao i dano objašnjenje zašto je ista upotrebljena.

U poglavlju \ref{ch:Hardware} opisan je izrađeni hardwareski elektronički sklop korišten za prikupljanje obrađenih podataka.
U dodatku \ref{ArduinoSource} priložen je izvorni kod koji se izvršava na Arduino mikroračunalu.

Poglavlje \ref{ch:Software} opisuje postupak izrade analize prikupljenih podataka.
Kompletna analiza nalazi se u dodatku \ref{AnalizaKretanjaVozila}.

Kompletan Git repozitorij ovog rada javno je dostupan na \url{https://github.com/KristijanCetina/BachelorThesis}

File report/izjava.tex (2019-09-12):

\chapter*{Izjava o samostalnosti izrade završnog rada}
Izjavljujem da sam završni rad na temu \textbf{\emph{Izrada snimača podataka, obrada i vizualizacija prikupljenih podataka bazirana na principima slobodnog i otvorenog koda}} samostalno izradio uz pomoć mentorice Sanje Grbac Babić mag. računarstva, koristeći navedenu stručnu literaturu i znanje stečeno tijekom studiranja.
Završni rad pisan je u duhu hrvatskoga jezika.
\vspace{\fill}
\begin{flushright}
Student: Kristijan Cetina\\
\vspace{15mm}
--------------------------------------------------------------
\end{flushright}

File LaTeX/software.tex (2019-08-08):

\chapter{Software}
U ovom pogljaću biti će opisana softwareska komponenta za obradu i vizualizaciju prikupljenih podataka.
\section{Prikupljanja podataka: software na Arduinu}
Sustav skuplja i sprema podatke sa GPS receivera kao i s temperaturnog senzora koje sprema u .csv \footnote{Comma Separated Values} formatu koji je pogodan za kasniju obradu bilo putem Excel programskog alata ili drugih alata za obradu i vizualizaciju podataka.

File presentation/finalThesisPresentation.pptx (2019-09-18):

## Izrada snimača podataka, obrada i vizualizacija prikupljenih podataka bazirana na principima slobodnog i otvorenog koda

Završni rad
Student: Kristijan Cetina
Mentorica: Sanja Grbac Babić, mag.ing.comp.
Pula, 20. rujna 2019.

## Uvod

- Hipoteza rada
  - primjena pristupa otvorenog i slobodnog koda (računalnog koda, metode obrade podataka, algoritama i shema hardwareskog sklopa) omogućava izradu funkcionalnog sustava uz prihvatljive troškove i skromne resurse.
- A to znači…
  - https://github.com/KristijanCetina/BachelorThesis

## Korištene tehnologije

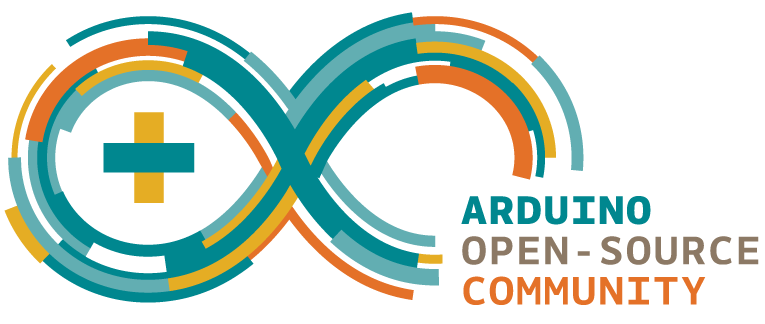
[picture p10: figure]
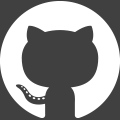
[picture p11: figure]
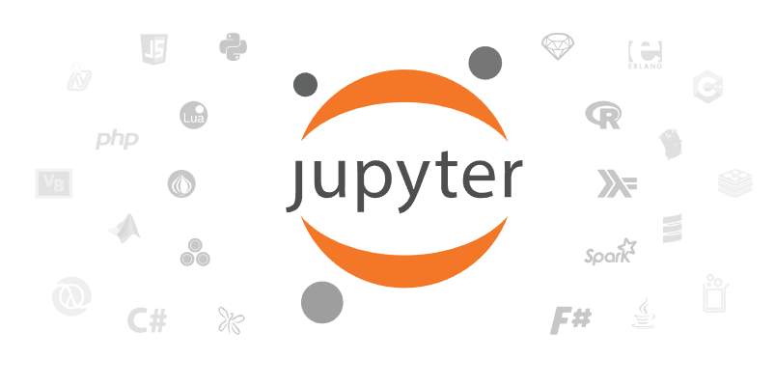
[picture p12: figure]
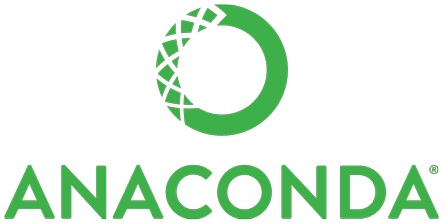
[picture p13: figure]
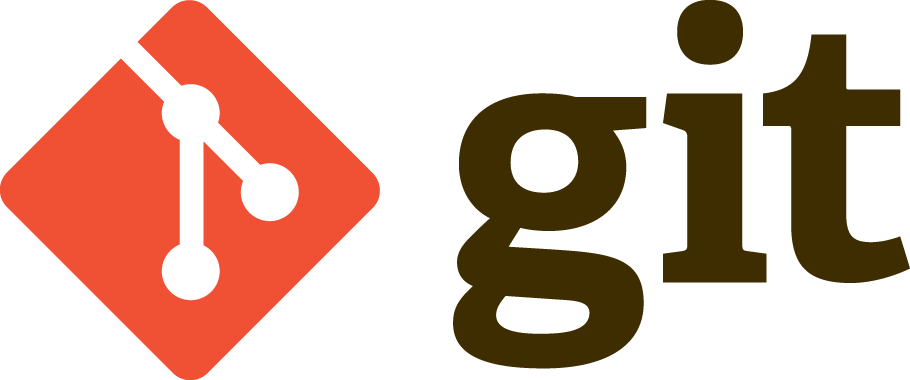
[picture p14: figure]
Image result for git logo
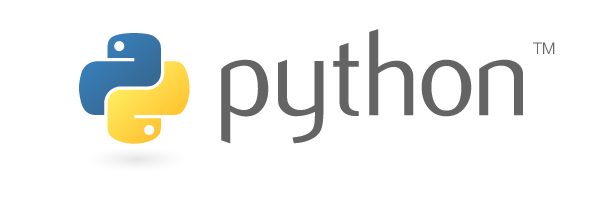
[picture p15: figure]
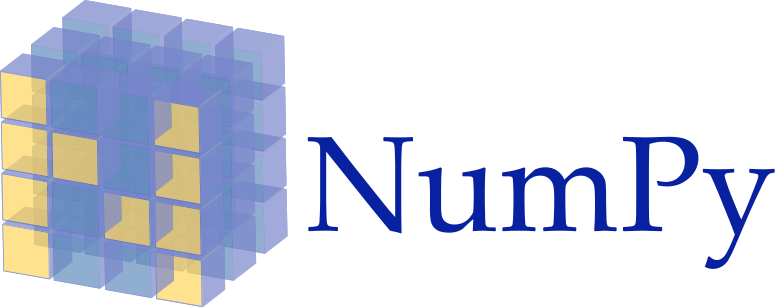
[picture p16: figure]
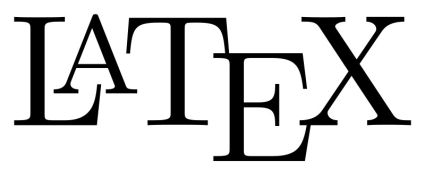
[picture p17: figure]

## Hardware i skupljanje podataka


## Temperaturni senzor

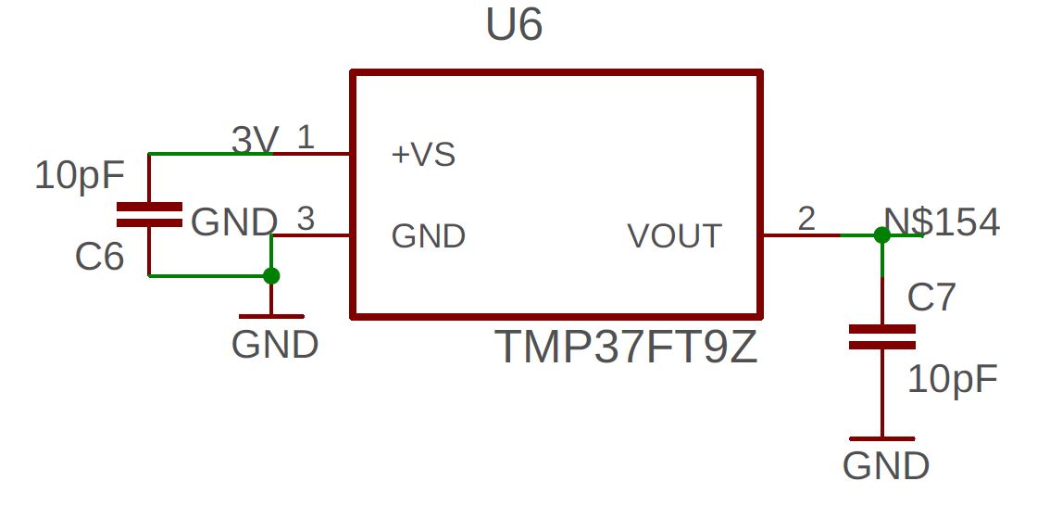
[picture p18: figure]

## Filtriranje signala

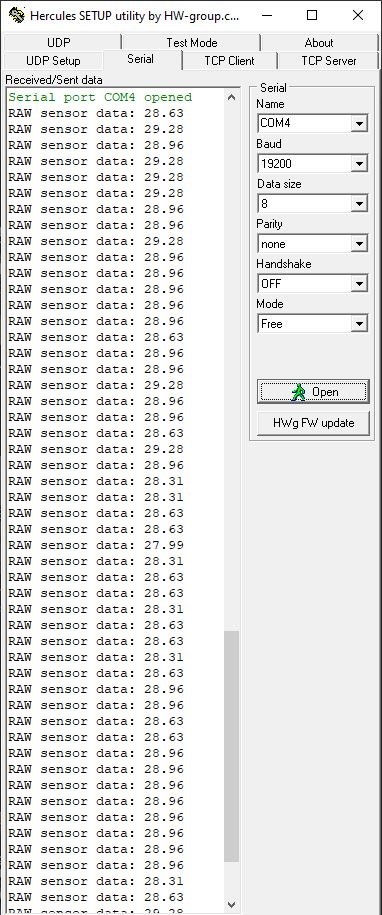
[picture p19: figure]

Nefiltrirani signal

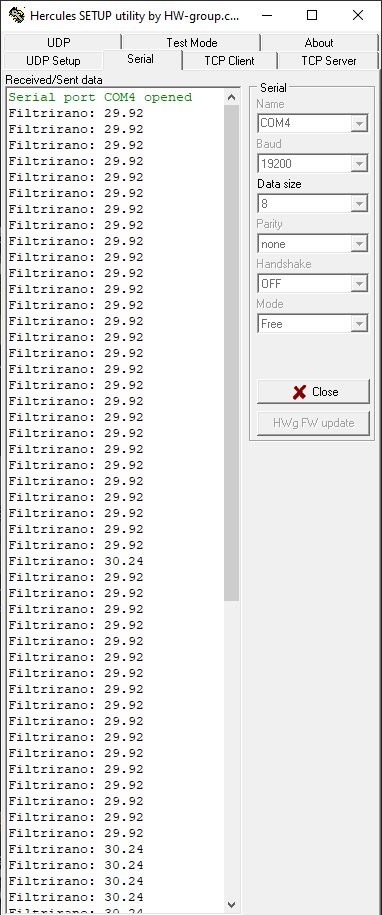
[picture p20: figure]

Softwareski filter

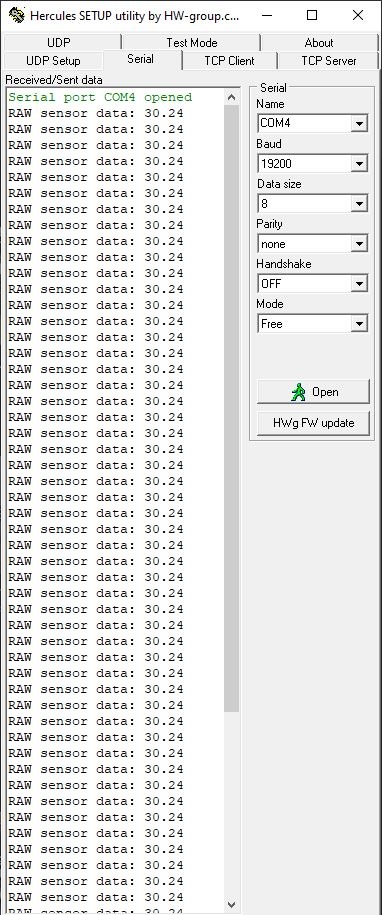
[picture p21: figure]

+ hardwareski filter

## GPS podaci

- $GPRMC – NMEA (0183) Recommended minimum specific GPS/Transit data
- NMEA - National Marine Electronics Association

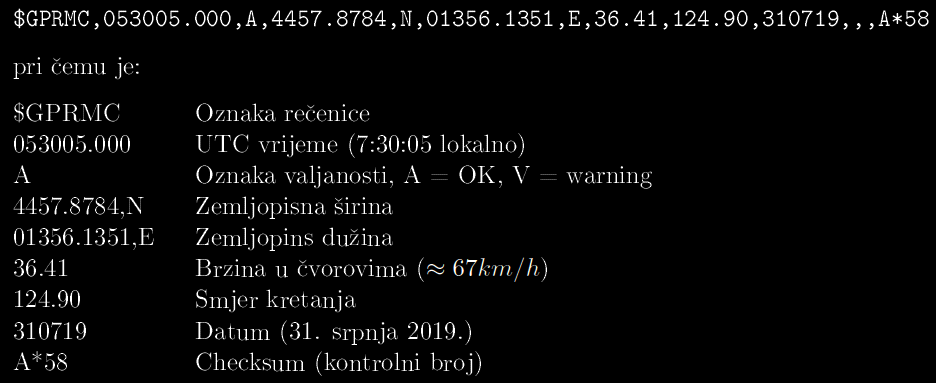
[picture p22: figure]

## Software i vizualizacija podataka

- Programski jezik Python
  - Jupyter notebook okruženje
  - NumPy i Pandas biblioteke za obradu podataka
  - Matplotlib za generiranje grafova

## Prednost korištenja NumPy

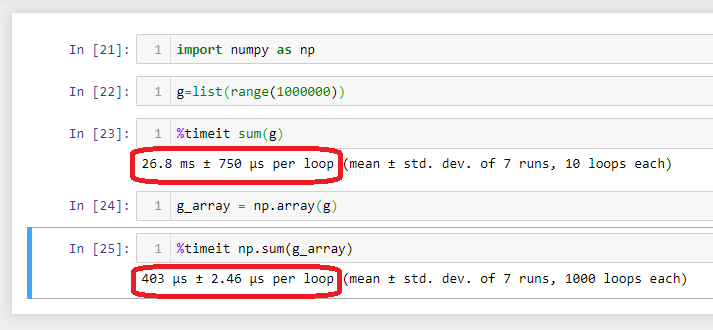
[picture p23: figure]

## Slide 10

DEMO

## Hvala na pažnji

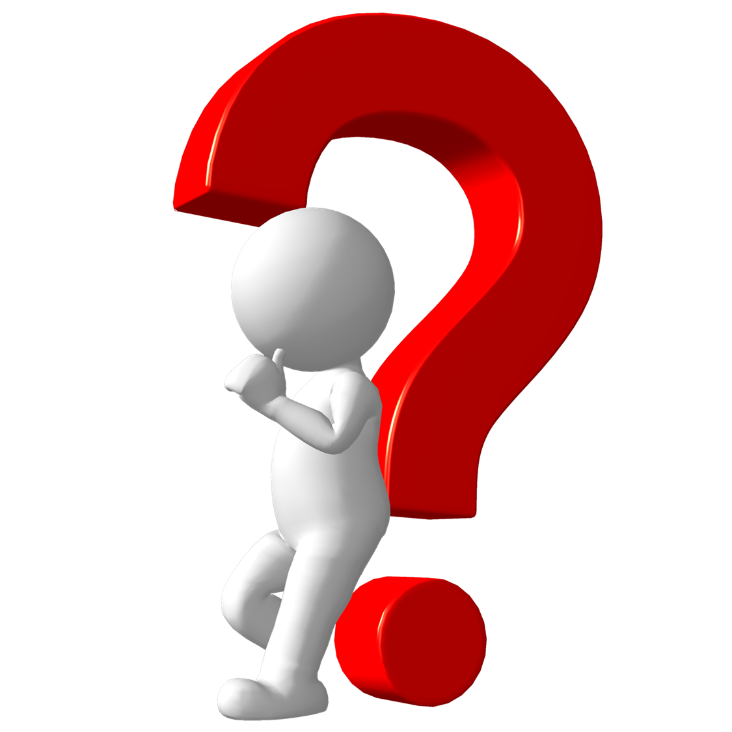
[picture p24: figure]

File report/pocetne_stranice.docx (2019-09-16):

ISTARSKO VELEUČILIŠTE – UNIVERSITÀ ISTRIANA

DI SCIENZE APPLICATE

Preddiplomski stručni studij Politehnike

ZAVRŠNI RAD

IZRADA SNIMAČA PODATAKA, OBRADA I VIZUALIZACIJA PRIKUPLJENIH PODATAKA BAZIRANA NA PRINCIPIMA SLOBODNOG I OTVORENOG KODA

Kristijan Cetina

PULA, rujan 2019.

ISTARSKO VELEUČILIŠTE – UNIVERSITÀ ISTRIANA

DI SCIENZE APPLICATE

Preddiplomski stručni studij Politehnike

ZAVRŠNI RAD

IZRADA SNIMAČA PODATAKA, OBRADA I VIZUALIZACIJA PRIKUPLJENIH PODATAKA BAZIRANA NA PRINCIPIMA SLOBODNOG I OTVORENOG KODA

Kolegij: Elektronika 2

Student: Kristijan Cetina

Mentor: Sanja Grbac Babić mag. računarstva, viši predavač

PULA, rujan2019.

Posveta

ZAHVALA:

Izjava o samostalnosti izrade završnog rada

Student:

Potpis: ___________

## Sažetak

Ključne riječi:

## Summary

Keywords:

## Popis oznaka i kratica

Oznaka Opis Jedinica

U napon V

I električna struja A

kapacitet električnih akumulatora Ah

Kratica Opis

CPU Central Processing Unit - procesor

# 1. UVOD

Tema za ovaj završni rad nastala je zbog osobne potrebe autora za uređajem iz naslova. Autoru se u više navrata dogodilo da je olovna akumulatorska baterija na plovilu u zimskom razdoblju stradala zbog nedovoljnog održavanja. Osim problema financijske prirode, zamjena akumulatorske baterije ima za posljedicu i ekološki faktor koji također nije zanemariv.

Slika 3: Blok shema pojednostavljenog mikrokontrolera

Izvor: Verde M., Pic Mikrokontroleri, Beograd : Mikroelektronika; 2008.

Do sada je prezentiran hardverski dio mikrokontrolera. No da bi on mogao izvršavati zadaće koje neki korisnik od njega zahtijeva mora postojati i programski kod. Veliki proboj u popularizaciji programiranja mikrokontrolera desio se predstavljanjem Arduino platforme.

# 2. DRUGO POGLAVLJE

# 3. ZAKLJUČAK

# 4. LITERATURA

[1 ] BatteryBasics How Do LeadAcidBatteriesWork? Dostupno na:

# 5. POPIS SLIKA

# 6. PRILOZI

Prilog 1: ESP8266 mikrokontroler

www.espress

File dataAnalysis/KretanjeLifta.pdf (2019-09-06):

# KretanjeLifta

## September 6, 2019

## 1 Kretanje lifta i prikaz ubrzanja

### Ova analiza prikazuje primjer vizualizacije podataka prikupljenih koristei phyphox ap-

likaciju dostupnu za mobilne telefone. Vie onformacija o ovoj aplikaciji moe se pronai na:

### https://phyphox.org/

Na | slici | je | prikazan | koordinatni | sustav | kojeg | koristi | aplikacija

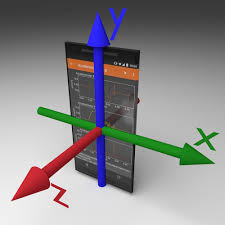
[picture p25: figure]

Podaci su zatim spremljeni u .csv datoteku i preneeni na raunalo. Datoteka je formatirana na nain da ima imena vrijednosti u zaglavlju te su koriteni zadani nazivi, a polja su odvojena znakom “;”

### Kao i u predhodnoj analizi potrebno je prvo uitati potrebne module

In [1]: import pandas as pd
import numpy as np
import matplotlib.pyplot as plt
from matplotlib import style

### Unese se ime datoteke s podacima u varijablu filename koristei jednostuke navodne znakove

In [2]: filename='Lift.csv'
#plt.style.use('ggplot')

data=pd.read_csv(filename, delimiter=';')

In [3]: #otvori graf u novom prozoru #%matplotlib qt

plt.rcParams["figure.figsize"] = (15,25)
fig, axs = plt.subplots(4, sharex=True, sharey=True)

axs[0].plot(data['Time (s)'],data['Linear Acceleration x (m/s^2)'], 'g-',linewidth=0.4) axs[0].set_title('Linear Acceleration x')
axs[0].set(ylabel='g [$m/s^2$]')

axs[1].plot(data['Time (s)'],data['Linear Acceleration y (m/s^2)'], 'b-',linewidth=0.4) axs[1].set_title('Linear Acceleration y')
axs[1].set(ylabel='g [$m/s^2$]')

axs[2].plot(data['Time (s)'],data['Linear Acceleration z (m/s^2)'], 'r-',linewidth=0.4) axs[2].set_title('Linear Acceleration z')
axs[2].set(ylabel='g [$m/s^2$]')

axs[3].plot(data['Time (s)'],data['Absolute acceleration (m/s^2)'], 'k-',linewidth=0.4) axs[3].set_title('Absolute acceleration $\sqrt{x^2+y^2+z^2}$')
axs[3].set(ylabel='|g| [$m/s^2$]')

for ax in axs.flat:
ax.set(xlabel='time [s]')

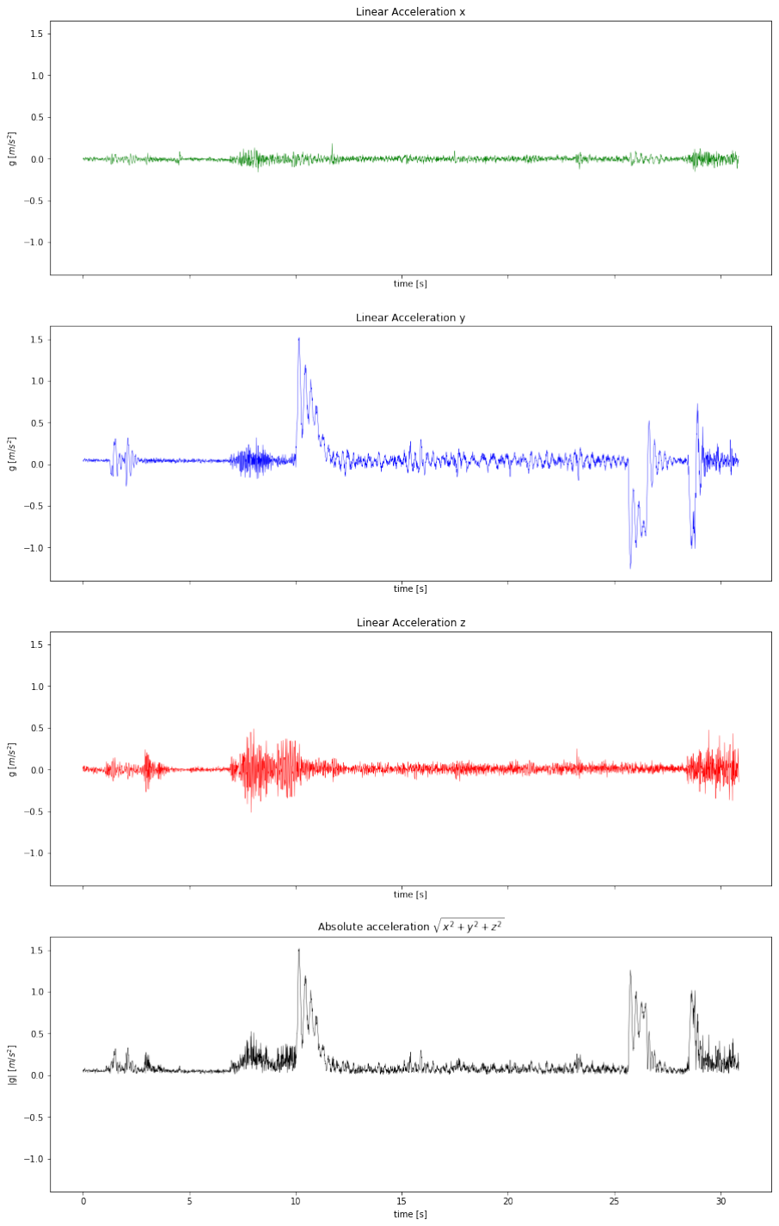
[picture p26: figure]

### Za probu zgodno je probati izraditi predhnodne grafove ali uz izmjenu da pojedini grafovi

nemaju istu visinu ordinate vec se automatski prilagode rasponu vrijednosti koristeci zamjenjujuci

### sljedecu liniju koda

fig, axs = plt.subplots(4, sharex=True, sharey=False)

S obzirom da je defaultna vrijednost tog parametra False moe se i izostaviti te pisati samo

fig, axs = plt.subplots(4, sharex=True)

### Prouciti kako ta promjena utjece na percepciju vrijednosti i vizualizaciju podataka

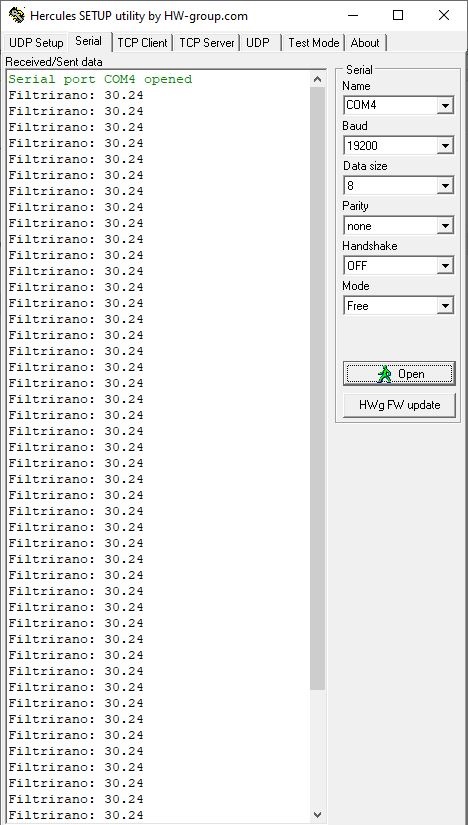
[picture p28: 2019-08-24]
tempSensor/FilteredWithCaps.JPG

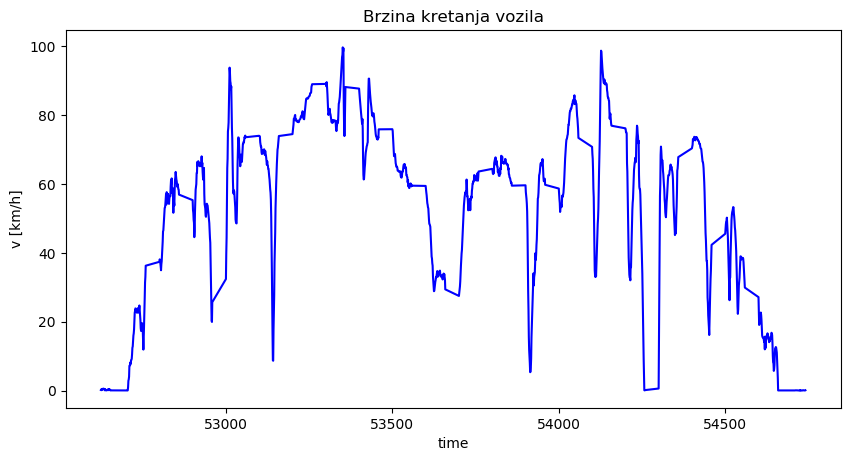
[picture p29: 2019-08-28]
dataAnalysis/GrafKretanjaBrzineVozila.png

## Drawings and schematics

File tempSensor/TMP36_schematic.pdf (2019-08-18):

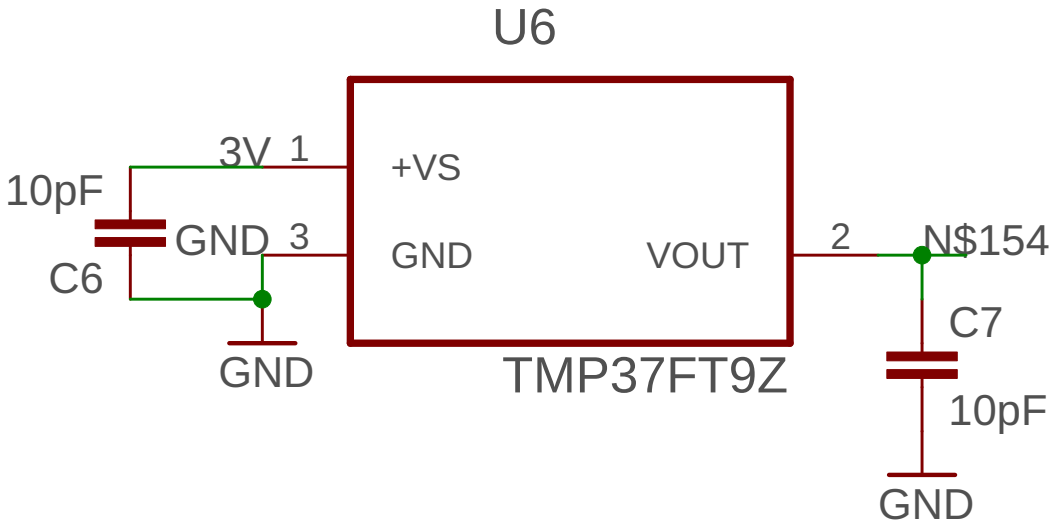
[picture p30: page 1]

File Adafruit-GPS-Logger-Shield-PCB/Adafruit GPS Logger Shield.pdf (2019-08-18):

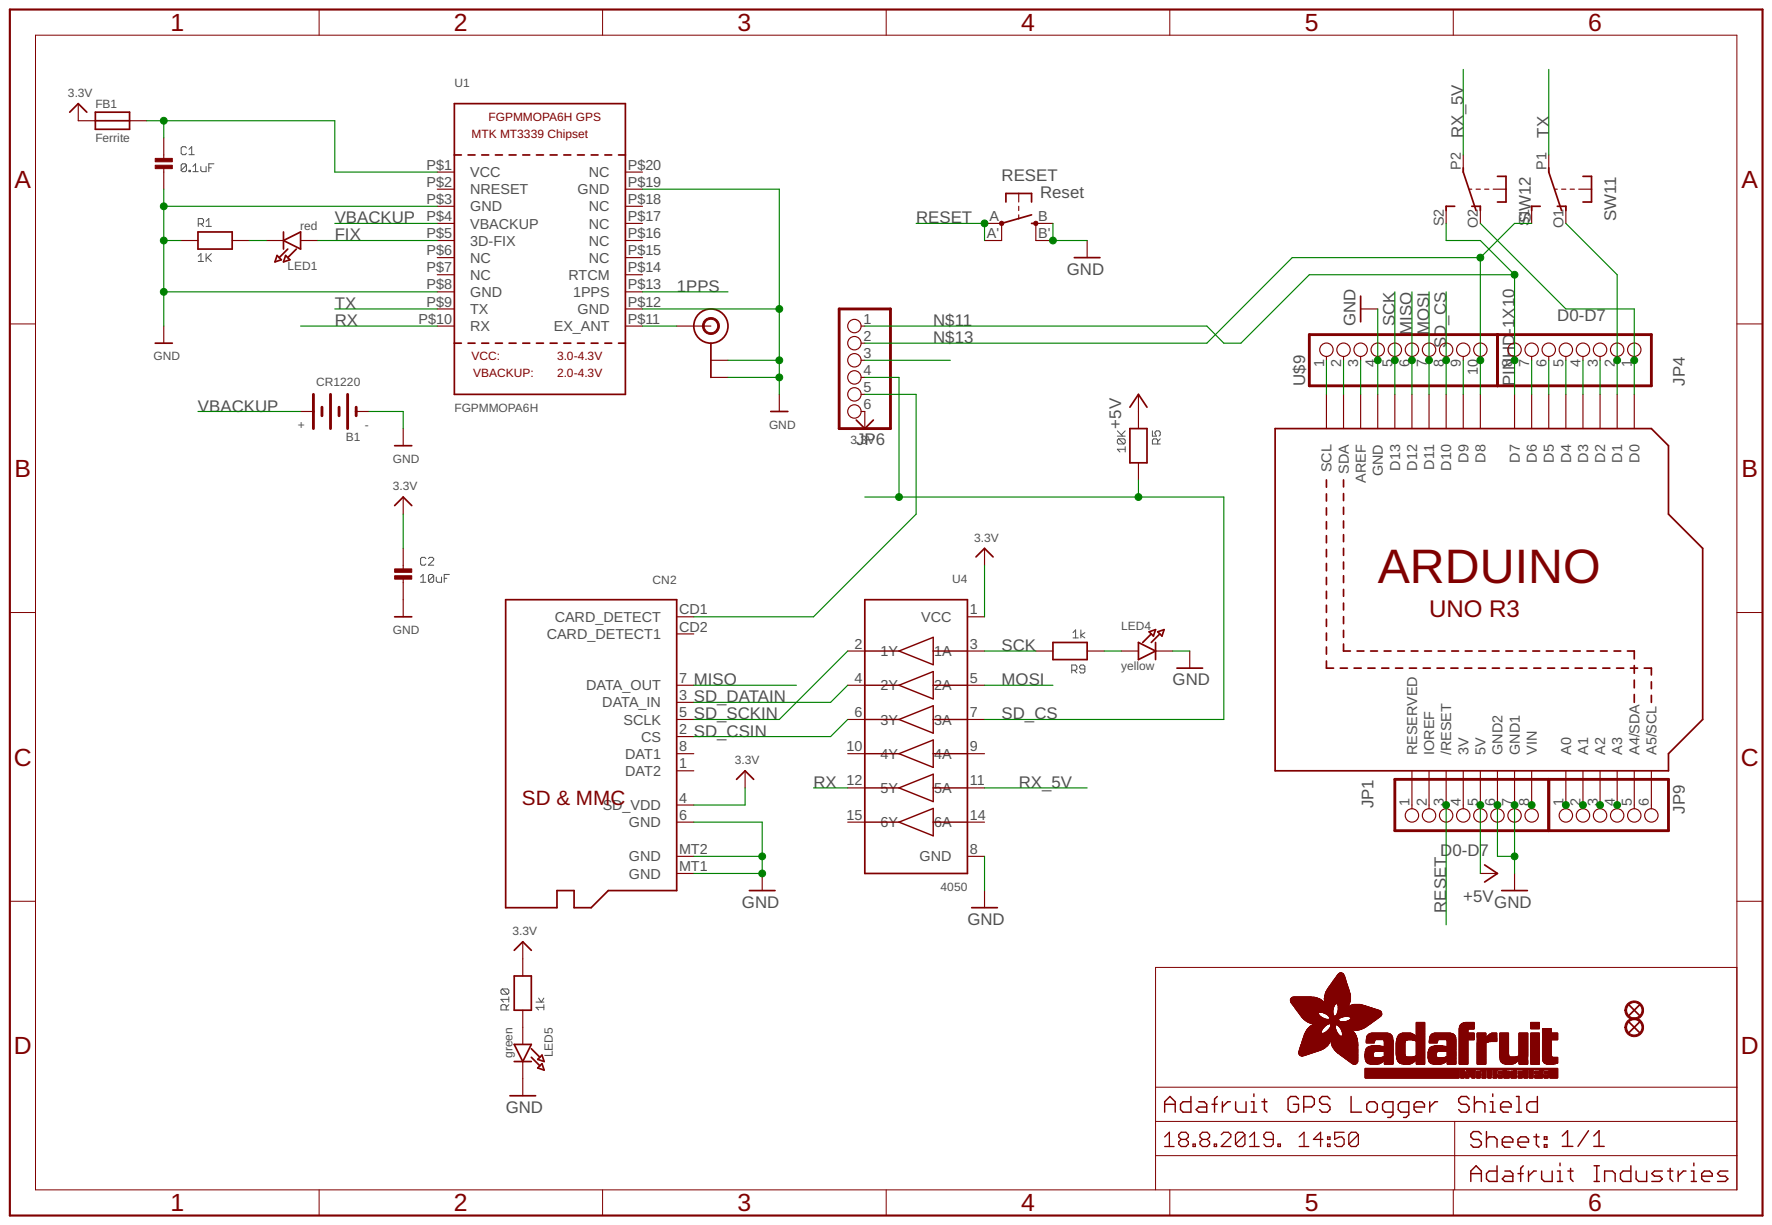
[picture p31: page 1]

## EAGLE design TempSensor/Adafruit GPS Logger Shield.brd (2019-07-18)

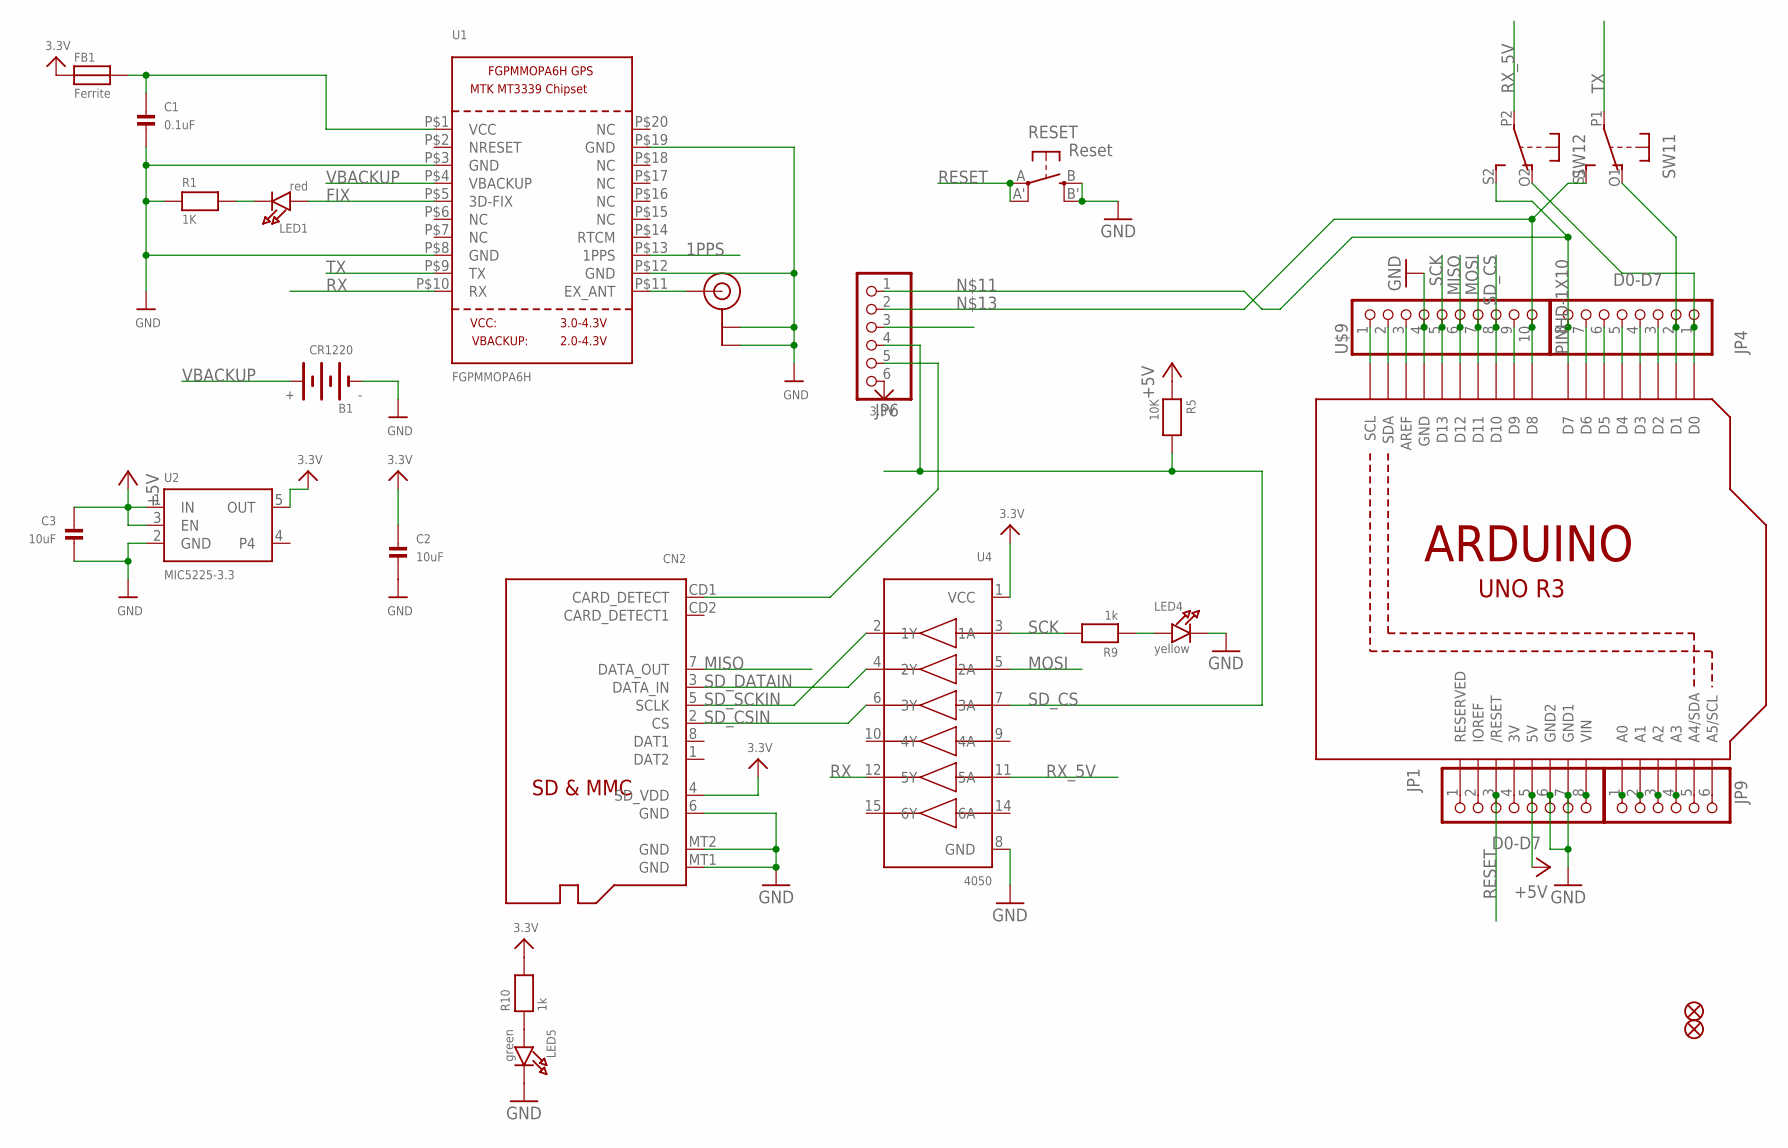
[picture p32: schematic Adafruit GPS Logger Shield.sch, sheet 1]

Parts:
B1: CR1220
C1: 0.1uF; 0805@1
C2, C3: 10uF; 0805@1
CN2: MICROSD
FB1: Ferrite; 0805@1
FID1, FID2: FIDUCIAL""; FIDUCIAL_1MM
JP1, JP4: D0-D7; 1X08-BIG
JP6, JP9: PINHD-1X6B; 1X06-BIG
LED1: red; CHIPLED_0805
LED4: yellow; CHIPLED_0805
LED5: green; CHIPLED_0805
R1: 1K; 0805
R5: 10K; 0805
R9, R10: 1k; 0805
RESET: Reset; EVQ-Q2
SW1: DPDT-EG1390; EG1390
U1: FGPMMOPA6H
U2: MIC5225-3.3; SOT23-5
U3: ARDUINOR3-DIMENSION; ARDUINOR3
U4: 4050; SOIC16
U$9: PINHD-1X10; 1X10-BIG
U$20: U.FL

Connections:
1PPS: JP6.3, U1.P$13 (1PPS)
3.3V: C2.1, CN2.4 (SD_VDD), FB1.1, JP6.6, R10.2, U2.5 (OUT), U4.1 (VCC)
+5V: C3.1, JP1.5, R5.1, U2.1 (IN), U2.3 (EN), U3.5V
FIX: LED1.A, U1.P$5 (3D-FIX)
GND: B1.-, C1.2, C2.2, C3.2, CN2.6 (GND), CN2.MT1 (GND), CN2.MT2 (GND), JP1.6, JP1.7, LED4.C, LED5.C, R1.1, RESET.B (S), RESET.B' (S1), U1.P$3 (GND), U1.P$8 (GND), U1.P$12 (GND), U1.P$19 (GND), U2.2 (GND), U3.GND, U3.GND1, U3.GND2, U4.8 (GND), U$9.4, U$20.P$1 (GND), U$20.P$2 (GND); also elsewhere on the board
MISO: CN2.7 (DATA_OUT), U3.D12, U$9.6
MOSI: U3.D11, U4.5 (2A), U$9.7
unnamed: C1.1, FB1.2, U1.P$1 (VCC)
unnamed: LED1.C, R1.2
unnamed: JP1.1, U3.RESERVED
unnamed: U1.P$11 (EX_ANT), U$20.P$3 (SIGNAL)
unnamed: JP1.2, U3.IOREF
unnamed: JP1.4, U3.3V
unnamed: U3.SCL, U$9.1
unnamed: LED4.A, R9.1
unnamed: JP9.6, U3.A5 (A5/SCL)
unnamed: JP9.5, U3.A4 (A4/SDA)
unnamed: JP4.8, JP6.1, SW1.S2 (S), U3.D7
unnamed: U3.SDA, U$9.2
unnamed: JP6.2, SW1.S1 (S), U3.D8, U$9.10
unnamed: JP4.2, SW1.O1 (O), U3.D1
unnamed: JP1.8, U3.VIN
unnamed: JP4.3, U3.D2
unnamed: JP4.4, U3.D3
unnamed: JP4.5, U3.D4
unnamed: JP4.6, U3.D5
unnamed: JP4.7, U3.D6
unnamed: U3.AREF, U$9.3
unnamed: U3.D9, U$9.9
unnamed: LED5.A, R10.1
unnamed 160: JP9.1, U3.A0; also elsewhere on the board
unnamed: JP9.2, U3.A1
unnamed: JP9.3, U3.A2
unnamed: JP9.4, U3.A3
unnamed: JP4.1, SW1.O2 (O), U3.D0
RESET: JP1.3, RESET.A, RESET.A' (P1), U3.RESET (/RESET)
RX: U1.P$10 (RX), U4.12 (5Y)
RX_5V: SW1.P2, U4.11 (5A)
SCK: R9.2, U3.D13, U4.3 (1A), U$9.5
SD_CD: CN2.CD1 (CARD_DETECT), JP6.5
SD_CS: JP6.4, R5.2, U3.D10, U4.7 (3A), U$9.8
SD_CSIN: CN2.2 (CS), U4.6 (3Y)
SD_DATAIN: CN2.3 (DATA_IN), U4.4 (2Y)
SD_SCKIN: CN2.5 (SCLK), U4.2 (1Y)
TX: SW1.P1, U1.P$9 (TX)
VBACKUP: B1.+$1 (+), U1.P$4 (VBACKUP)

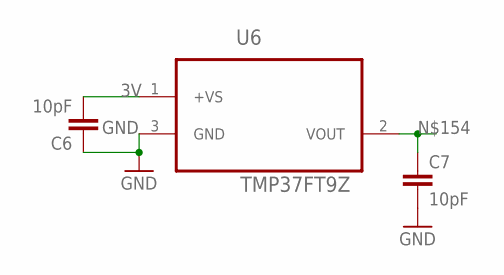
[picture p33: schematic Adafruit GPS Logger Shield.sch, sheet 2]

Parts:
C6, C7: 10pF; C2.5-3
U6: TMP37FT9Z; TO254P508X660-3P

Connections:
3V: C6.2, U6.1 (+VS)
GND: C6.1, C7.2, U6.3 (GND); also elsewhere on the board
unnamed 160: C7.1, U6.2 (VOUT); also elsewhere on the board

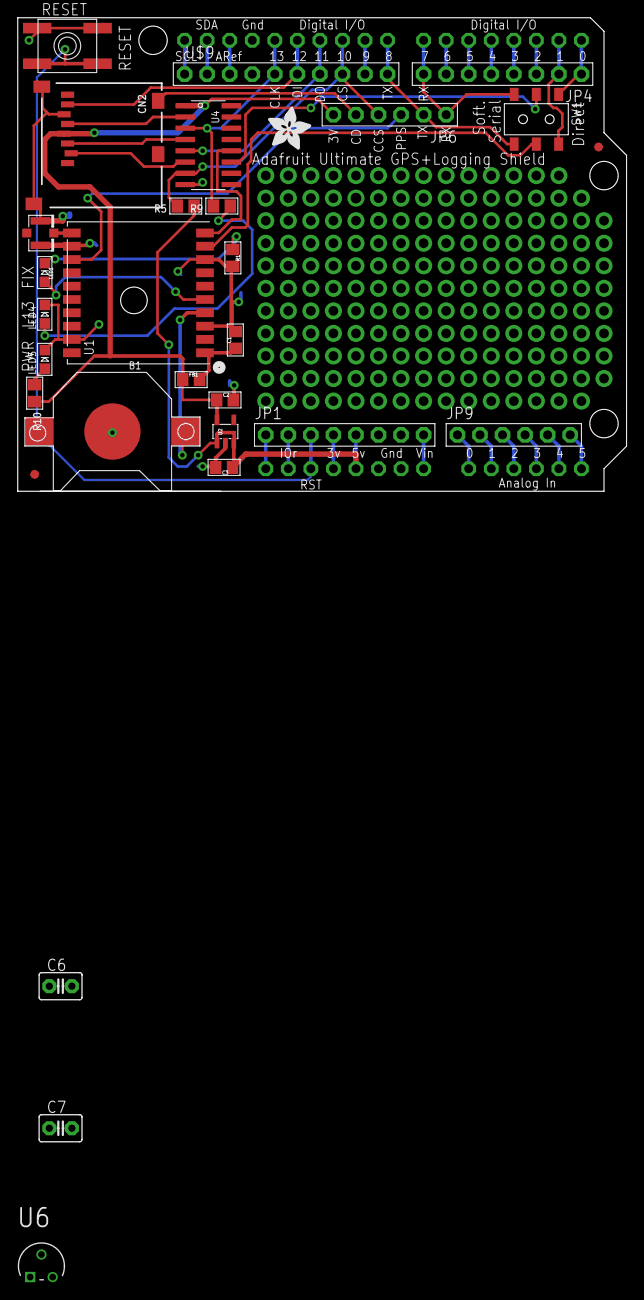
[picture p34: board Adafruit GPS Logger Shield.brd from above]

Board: 2 copper layers, 68.6 x 53.3 mm, 32 parts (1 on the bottom side), 47 nets.

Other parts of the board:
U$13: ADAFRUIT_5MM
U$15: ADAFRUIT_TEXT_30MM

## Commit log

2019-07-18 added adafruit GPS shield files
    [Adafruit GPS Logger Shield.brd, Adafruit GPS Logger Shield.sch]
2019-07-18 added TMP36 circuitry
    [Adafruit GPS Logger Shield.brd, Adafruit GPS Logger Shield.sch]
2019-08-07 Added data sources
    [GPSLOG03.CSV, GPSLOG10.CSV]
2019-08-18 malo o hardwareu
    [Adafruit GPS Logger Shield.sch]
2019-09-05 dodan put lifta
    [GPSLOG03.CSV, Lift.csv]
